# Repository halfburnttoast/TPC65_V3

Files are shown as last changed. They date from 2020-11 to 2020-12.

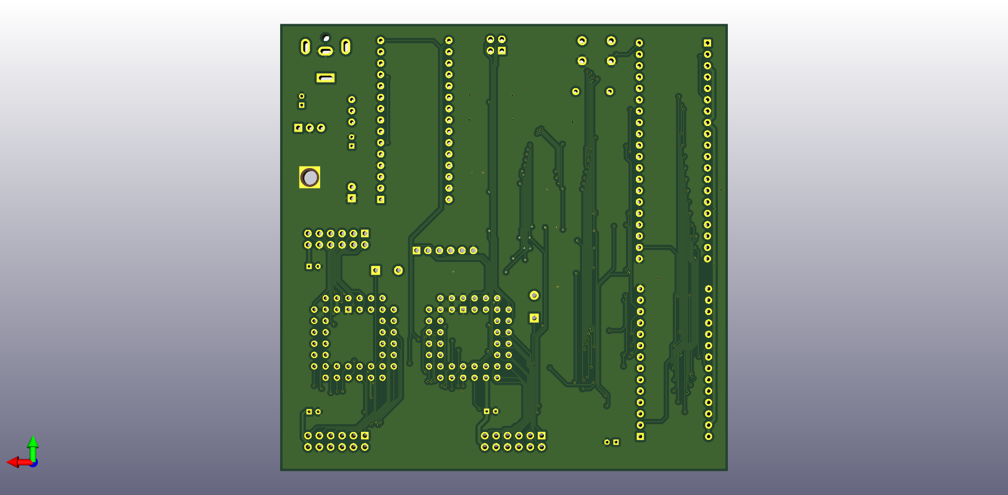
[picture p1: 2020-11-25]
tpc65816b.png

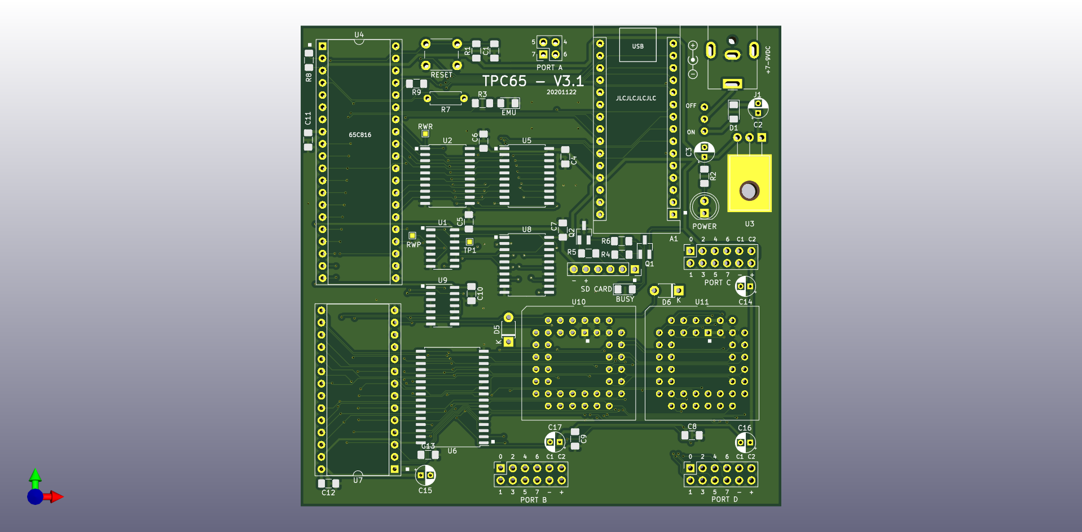
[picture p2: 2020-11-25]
tpc65816f.png

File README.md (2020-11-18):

# TPC65_V3
65C816 computer madness

This build replaces the TPC65-V2's CPU with a 65C816. It offers massive improvements, but requires additional circuitry to use bank switching.
On first boot, the CPU defaults to emulation mode. In emulation mode, the computer should be completely backwards compatible with V2 of this computer and all sofware. 

When emulation mode is turned off (see 65C816 datasheet for opcode sequence), the computer switches to 16-bit mode with a 24-bit (banked) address bus. 

Unfortunately, because of emulation mode, EEPROM must be located at the top-end of page 1 (0x000000 - 0x00FFFF). Because it follows the same memory map as V2, the memory map looks like this:

0x000000-0x007FFF - Base SRAM

0x008000-0x00BFFF - Memory-mapped IO

0x00C000-0x00FFFF - Base EEPROM + system vectors

Anything at or above 0x010000 is extended memory and requires banking through the 74x573 and 74x245. https://www.westerndesigncenter.com/wdc/documentation/w65c816s.pdf (page-44). 

The extended memory is currently mapped to the remaining address pins of the SRAM, which should give about 450K of extended RAM. Expanding EEPROM is not a priority as this computer has a built-in SD card module slot and is inteded to use the SD card for larger program loading.

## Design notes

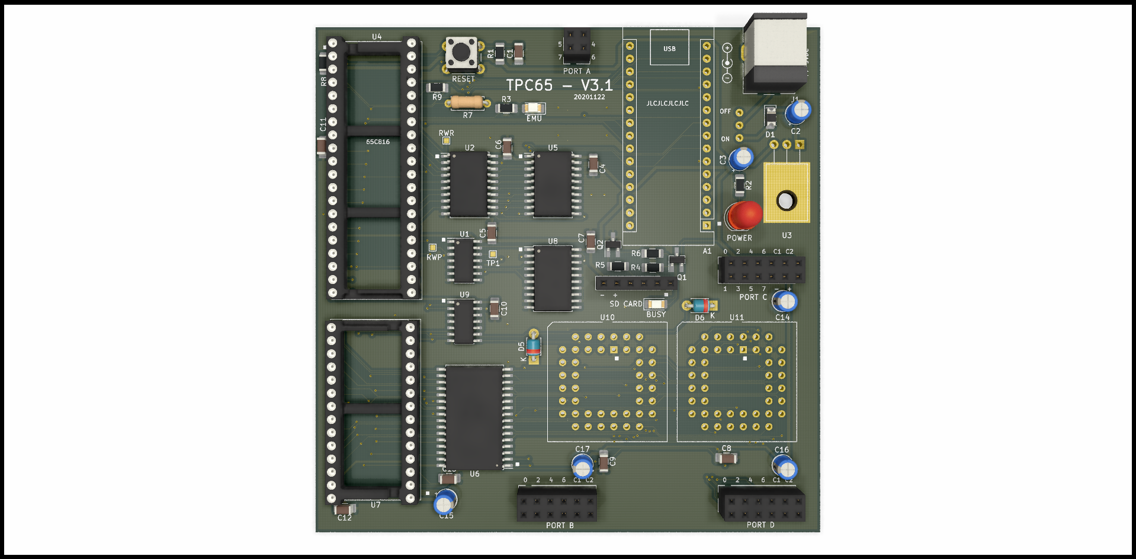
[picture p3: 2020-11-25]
tpc65816.png

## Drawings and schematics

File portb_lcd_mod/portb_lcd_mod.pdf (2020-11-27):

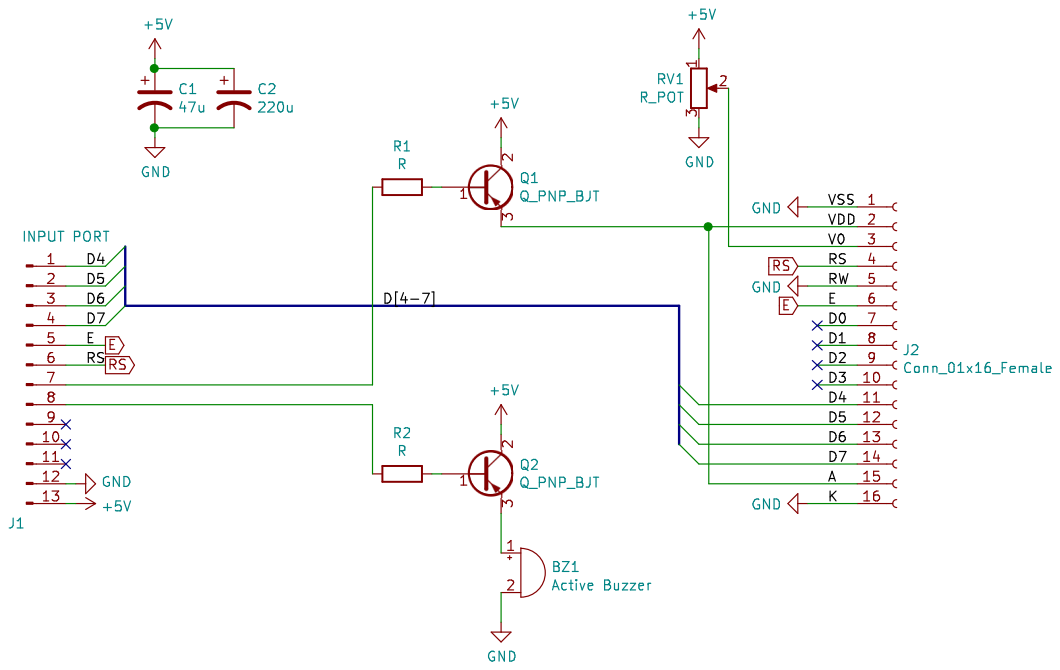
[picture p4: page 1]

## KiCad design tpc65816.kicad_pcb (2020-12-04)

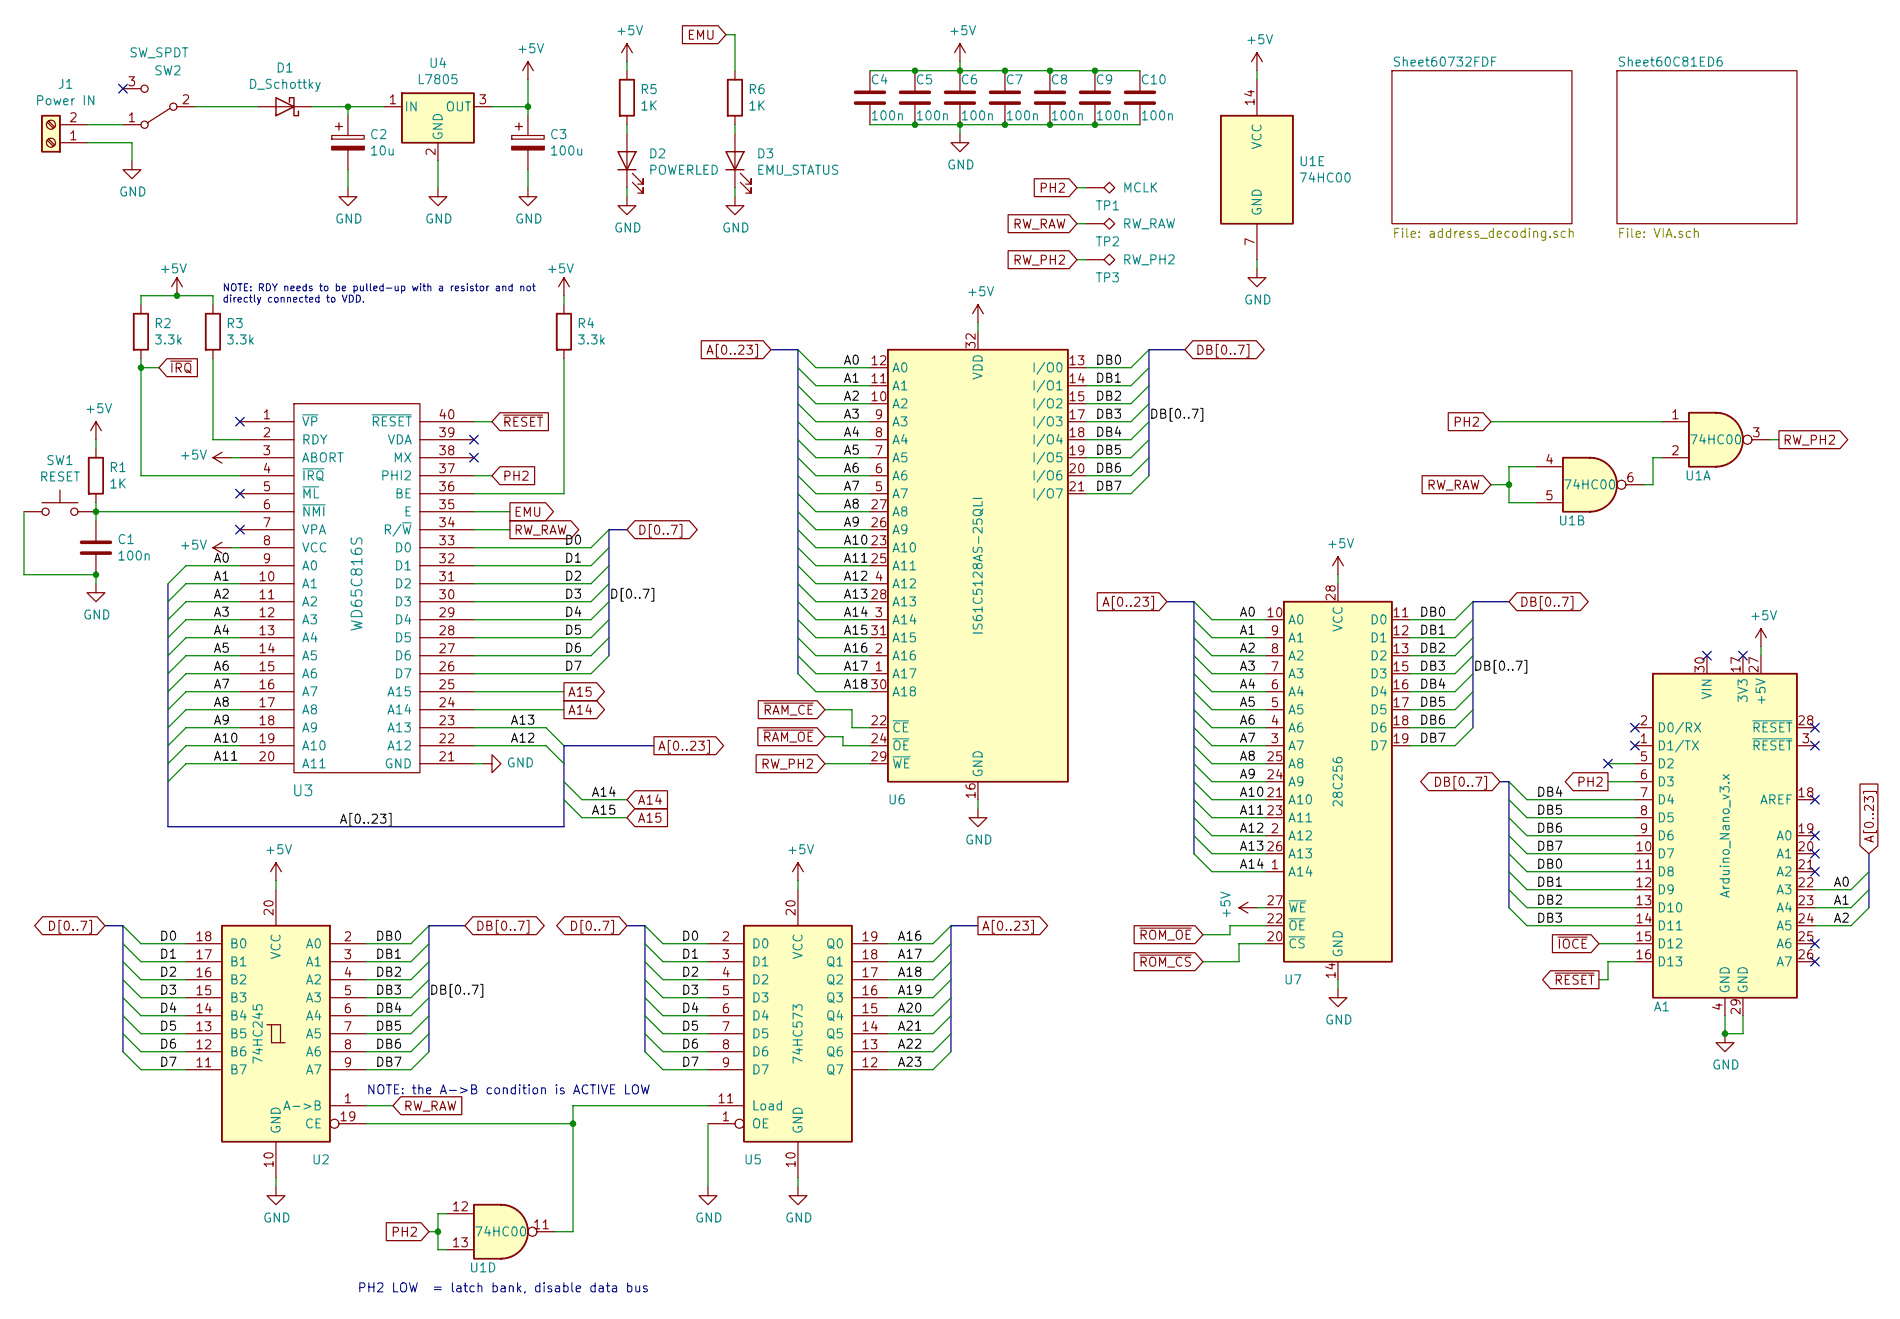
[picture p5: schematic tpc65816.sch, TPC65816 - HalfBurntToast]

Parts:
A1: Arduino_Nano_v3.x; Arduino_Nano
C1, C4, C5, C6, C7, C8, C9, C10: 100n; C_1206_3216Metric_Pad1.42x1.75mm_HandSolder
C2: 10u; CP_Radial_D4.0mm_P2.00mm
C3: 100u; CP_Radial_D4.0mm_P2.00mm
D1: D_Schottky; D_1206_3216Metric_Pad1.42x1.75mm_HandSolder
D2: POWERLED; LED_D5.0mm
D3: EMU_STATUS; LED_1206_3216Metric_Pad1.42x1.75mm_HandSolder
J1: Power IN; TerminalBlock_bornier-2_P5.08mm
R1, R5, R6: 1K; R_1206_3216Metric_Pad1.42x1.75mm_HandSolder
R2: 3.3k; R_Axial_DIN0207_L6.3mm_D2.5mm_P7.62mm_Horizontal
R3, R4: 3.3k; R_1206_3216Metric_Pad1.42x1.75mm_HandSolder
SW1: RESET; SW_PUSH_6mm
SW2: SW_SPDT; spdt_slide_switch
TP1: MCLK; TestPoint_Pad_1.0x1.0mm
TP2: RW_RAW; TestPoint_Pad_1.0x1.0mm
TP3: RW_PH2; TestPoint_Pad_1.0x1.0mm
U1: 74HC00; SOIC-14_3.9x8.7mm_P1.27mm
U2: 74HC245; SOIC-20W_7.5x12.8mm_P1.27mm
U3: WD65C816S; DIP-40_W15.24mm_Socket
U4: L7805; TO-220F-3_Horizontal_TabDown
U5: 74HC573; SOIC-20W_7.5x12.8mm_P1.27mm
U6: IS61C5128AS-25QLI; SSOP-32_11.305x20.495mm_P1.27mm
U7: 28C256; DIP-28_W15.24mm_Socket

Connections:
+5V: A1.27 (+5V), C3.1, C4.1, C5.1, C6.1, C7.1, C8.1, C9.1, C10.1, R1.1, R2.1, R3.1, R4.1, R5.1, U1.14 (VCC), U2.20 (VCC), U3.3 (ABORT), U3.8 (VCC), U4.3 (OUT), U5.20 (VCC), U6.32 (VDD), U7.27 (~WE), U7.28 (VCC); also elsewhere on the board
A0: A1.22 (A3), U3.9 (A0), U6.12 (A0), U7.10 (A0)
A1: A1.23 (A4), U3.10 (A1), U6.11 (A1), U7.9 (A1)
A2: A1.24 (A5), U3.11 (A2), U6.10 (A2), U7.8 (A2)
A3: U3.12 (A3), U6.9 (A3), U7.7 (A3); also elsewhere on the board
A4: U3.13 (A4), U6.8 (A4), U7.6 (A4); also elsewhere on the board
A5: U3.14 (A5), U6.7 (A5), U7.5 (A5); also elsewhere on the board
A6: U3.15 (A6), U6.6 (A6), U7.4 (A6); also elsewhere on the board
A7: U3.16 (A7), U6.5 (A7), U7.3 (A7); also elsewhere on the board
A8: U3.17 (A8), U6.27 (A8), U7.25 (A8); also elsewhere on the board
A9: U3.18 (A9), U6.26 (A9), U7.24 (A9)
A10: U3.19 (A10), U6.23 (A10), U7.21 (A10)
A11: U3.20 (A11), U6.25 (A11), U7.23 (A11)
A12: U3.22 (A12), U6.4 (A12), U7.2 (A12)
A13: U3.23 (A13), U6.28 (A13), U7.26 (A13)
A14: U3.24 (A14), U6.3 (A14), U7.1 (A14); also elsewhere on the board
A15: U3.25 (A15), U6.31 (A15); also elsewhere on the board
A16: U5.19 (Q0), U6.2 (A16); also elsewhere on the board
A17: U5.18 (Q1), U6.1 (A17); also elsewhere on the board
A18: U5.17 (Q2), U6.30 (A18); also elsewhere on the board
A19: U5.16 (Q3); also elsewhere on the board
A20: U5.15 (Q4); also elsewhere on the board
A21: U5.14 (Q5); also elsewhere on the board
A22: U5.13 (Q6); also elsewhere on the board
A23: U5.12 (Q7); also elsewhere on the board
D0: U2.18 (B0), U3.33 (D0), U5.2 (D0)
D1: U2.17 (B1), U3.32 (D1), U5.3 (D1)
D2: U2.16 (B2), U3.31 (D2), U5.4 (D2)
D3: U2.15 (B3), U3.30 (D3), U5.5 (D3)
D4: U2.14 (B4), U3.29 (D4), U5.6 (D4)
D5: U2.13 (B5), U3.28 (D5), U5.7 (D5)
D6: U2.12 (B6), U3.27 (D6), U5.8 (D6)
D7: U2.11 (B7), U3.26 (D7), U5.9 (D7)
DB0: A1.11 (D8), U2.2 (A0), U6.13 (I/O0), U7.11 (D0); also elsewhere on the board
DB1: A1.12 (D9), U2.3 (A1), U6.14 (I/O1), U7.12 (D1); also elsewhere on the board
DB2: A1.13 (D10), U2.4 (A2), U6.15 (I/O2), U7.13 (D2); also elsewhere on the board
DB3: A1.14 (D11), U2.5 (A3), U6.17 (I/O3), U7.15 (D3); also elsewhere on the board
DB4: A1.7 (D4), U2.6 (A4), U6.18 (I/O4), U7.16 (D4); also elsewhere on the board
DB5: A1.8 (D5), U2.7 (A5), U6.19 (I/O5), U7.17 (D5); also elsewhere on the board
DB6: A1.9 (D6), U2.8 (A6), U6.20 (I/O6), U7.18 (D6); also elsewhere on the board
DB7: A1.10 (D7), U2.9 (A7), U6.21 (I/O7), U7.19 (D7); also elsewhere on the board
EMU: R6.1, U3.35 (E)
GND: A1.4 (GND), A1.29 (GND), C1.2, C2.2, C3.2, C4.2, C5.2, C6.2, C7.2, C8.2, C9.2, C10.2, D2.1 (K), D3.1 (K), J1.1, SW1.1, U1.7 (GND), U2.10 (GND), U3.21 (GND), U4.2 (GND), U5.1 (OE), U5.10 (GND), U6.16 (GND), U7.14 (GND); also elsewhere on the board
unnamed: C1.1, R1.2, SW1.2, U3.6 (~NMI)
unnamed: C2.1, D1.1 (K), U4.1 (IN)
unnamed: D1.2 (A), SW2.2 (B)
unnamed: D2.2 (A), R5.2
unnamed: D3.2 (A), R6.2
unnamed: J1.2, SW2.1 (A)
unnamed: R3.2, U3.2 (RDY)
unnamed: R4.2, U3.36 (BE)
unnamed: U1.2, U1.6
unnamed: U1.11, U2.19 (CE), U5.11 (Load)
PH2: A1.6 (D3), TP1.1, U1.1, U1.12, U1.13, U3.37 (PHI2); also elsewhere on the board
RW_PH2: TP3.1, U1.3, U6.29 (~WE)
RW_RAW: TP2.1, U1.4, U1.5, U2.1 (A->B), U3.34 (R/~W); also elsewhere on the board
~IOCE: A1.15 (D12); also elsewhere on the board
~IRQ: R2.2, U3.4 (~IRQ); also elsewhere on the board
~RAM_CE: U6.22 (~CE), U6.24 (~OE); also elsewhere on the board
~RESET: A1.16 (D13), U3.40 (~RESET); also elsewhere on the board
~ROM_CS: U7.20 (~CS), U7.22 (~OE); also elsewhere on the board

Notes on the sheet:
NOTE: RDY needs to be pulled-up with a resistor and not directly connected to VDD.
NOTE: the A->B condition is ACTIVE LOW
PH2 LOW = latch bank, disable data bus

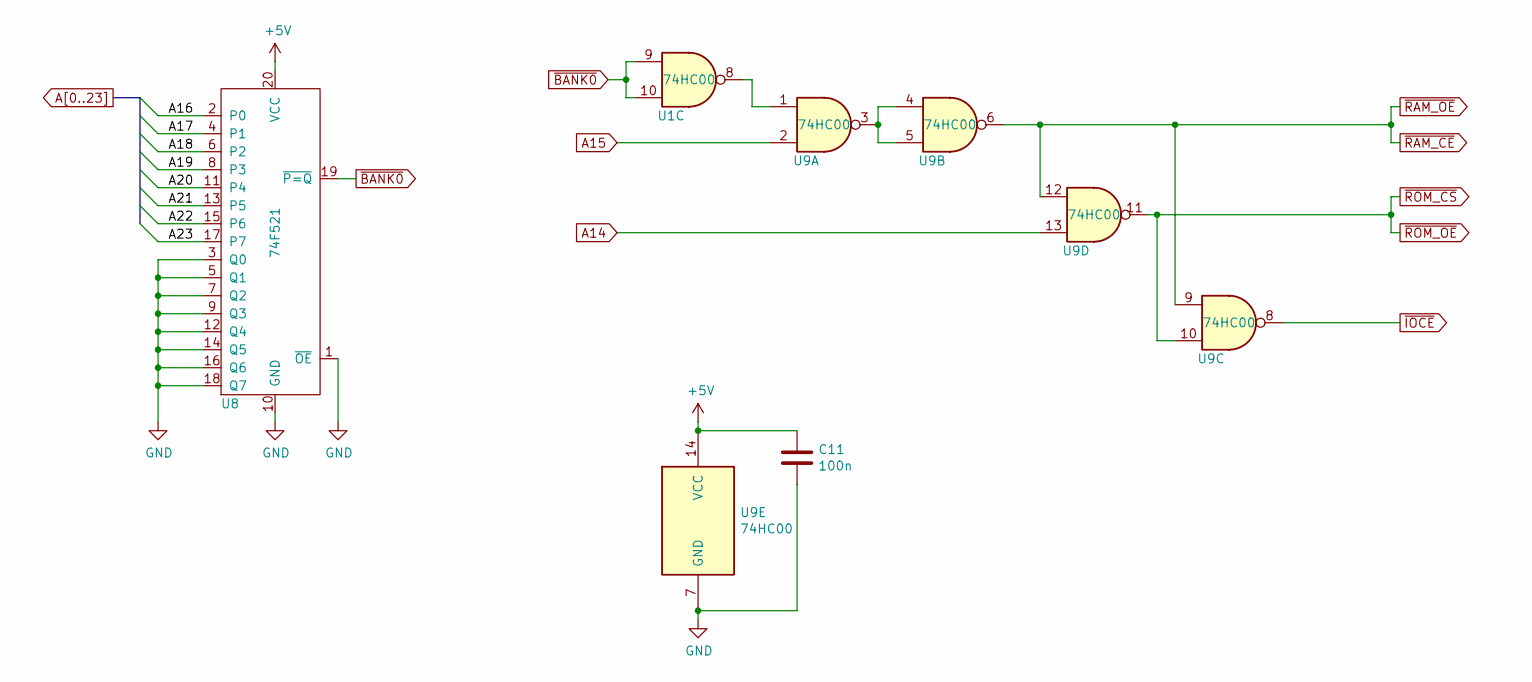
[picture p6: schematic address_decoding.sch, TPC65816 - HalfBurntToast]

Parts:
C11: 100n; C_1206_3216Metric_Pad1.42x1.75mm_HandSolder
U1, U9: 74HC00; SOIC-14_3.9x8.7mm_P1.27mm
U8: 74F521; SOIC-20W_7.5x12.8mm_P1.27mm

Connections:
+5V: C11.1, U8.20 (VCC), U9.14 (VCC); also elsewhere on the board
A14: U9.13; also elsewhere on the board
A15: U9.2; also elsewhere on the board
A16: U8.2 (P0); also elsewhere on the board
A17: U8.4 (P1); also elsewhere on the board
A18: U8.6 (P2); also elsewhere on the board
A19: U8.8 (P3); also elsewhere on the board
A20: U8.11 (P4); also elsewhere on the board
A21: U8.13 (P5); also elsewhere on the board
A22: U8.15 (P6); also elsewhere on the board
A23: U8.17 (P7); also elsewhere on the board
GND: C11.2, U8.1 (~OE), U8.3 (Q0), U8.5 (Q1), U8.7 (Q2), U8.9 (Q3), U8.10 (GND), U8.12 (Q4), U8.14 (Q5), U8.16 (Q6), U8.18 (Q7), U9.7 (GND); also elsewhere on the board
unnamed: U1.8, U9.1
unnamed: U9.3, U9.4, U9.5
~BANK0: U1.9, U1.10, U8.19 (~P=Q)
~IOCE: U9.8; also elsewhere on the board
~RAM_CE: U9.6, U9.9, U9.12; also elsewhere on the board
~ROM_CS: U9.10, U9.11; also elsewhere on the board

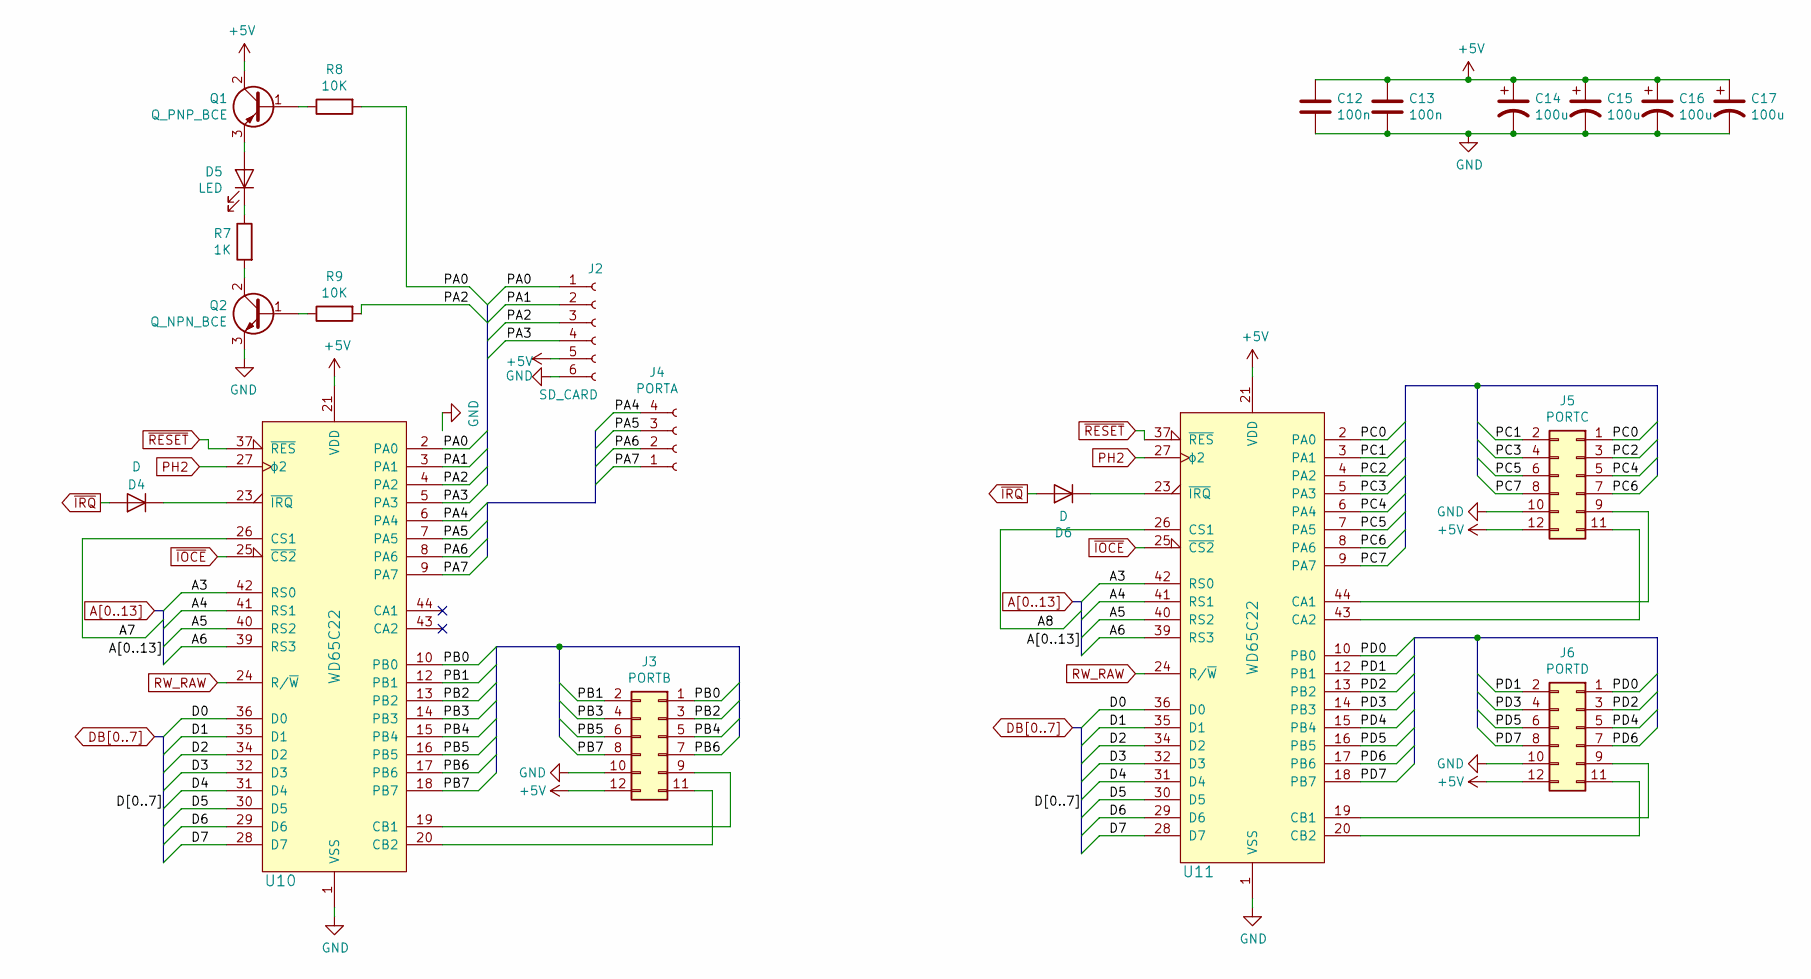
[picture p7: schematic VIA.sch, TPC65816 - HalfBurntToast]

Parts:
C12, C13: 100n; C_1206_3216Metric_Pad1.42x1.75mm_HandSolder
C14, C15, C16, C17: 100u; CP_Radial_D4.0mm_P2.00mm
D4, D6: D; D_T-1_P5.08mm_Horizontal
D5: LED; LED_1206_3216Metric_Pad1.42x1.75mm_HandSolder
J2: SD_CARD; PinSocket_1x06_P2.54mm_Vertical
J3: PORTB; PinSocket_2x06_P2.54mm_Vertical
J4: PORTA; PinSocket_2x02_P2.54mm_Vertical
J5: PORTC; PinSocket_2x06_P2.54mm_Vertical
J6: PORTD; PinSocket_2x06_P2.54mm_Vertical
Q1: Q_PNP_BCE; SOT-23_Handsoldering
Q2: Q_NPN_BCE; SOT-23_Handsoldering
R7: 1K; R_1206_3216Metric_Pad1.42x1.75mm_HandSolder
R8, R9: 10K; R_1206_3216Metric_Pad1.42x1.75mm_HandSolder
U10, U11: WD65C22; PLCC-44_THT-Socket

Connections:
+5V: C12.1, C13.1, C14.1, C15.1, C16.1, C17.1, J2.5, J3.12, J5.12, J6.12, Q1.2 (C), U10.21 (VDD), U11.21 (VDD); also elsewhere on the board
/Sheet60C81ED6/PA0: J2.1, R8.2, U10.2 (PA0)
/Sheet60C81ED6/PA1: J2.2, U10.3 (PA1)
/Sheet60C81ED6/PA2: J2.3, R9.2, U10.4 (PA2)
/Sheet60C81ED6/PA3: J2.4, U10.5 (PA3)
/Sheet60C81ED6/PA4: J4.4, U10.6 (PA4)
/Sheet60C81ED6/PA5: J4.3, U10.7 (PA5)
/Sheet60C81ED6/PA6: J4.2, U10.8 (PA6)
/Sheet60C81ED6/PA7: J4.1, U10.9 (PA7)
/Sheet60C81ED6/PB0: J3.1, U10.10 (PB0)
/Sheet60C81ED6/PB1: J3.2, U10.12 (PB1)
/Sheet60C81ED6/PB2: J3.3, U10.13 (PB2)
/Sheet60C81ED6/PB3: J3.4, U10.14 (PB3)
/Sheet60C81ED6/PB4: J3.5, U10.15 (PB4)
/Sheet60C81ED6/PB5: J3.6, U10.16 (PB5)
/Sheet60C81ED6/PB6: J3.7, U10.17 (PB6)
/Sheet60C81ED6/PB7: J3.8, U10.18 (PB7)
/Sheet60C81ED6/PC0: J5.1, U11.2 (PA0)
/Sheet60C81ED6/PC1: J5.2, U11.3 (PA1)
/Sheet60C81ED6/PC2: J5.3, U11.4 (PA2)
/Sheet60C81ED6/PC3: J5.4, U11.5 (PA3)
/Sheet60C81ED6/PC4: J5.5, U11.6 (PA4)
/Sheet60C81ED6/PC5: J5.6, U11.7 (PA5)
/Sheet60C81ED6/PC6: J5.7, U11.8 (PA6)
/Sheet60C81ED6/PC7: J5.8, U11.9 (PA7)
/Sheet60C81ED6/PD0: J6.1, U11.10 (PB0)
/Sheet60C81ED6/PD1: J6.2, U11.12 (PB1)
/Sheet60C81ED6/PD2: J6.3, U11.13 (PB2)
/Sheet60C81ED6/PD3: J6.4, U11.14 (PB3)
/Sheet60C81ED6/PD4: J6.5, U11.15 (PB4)
/Sheet60C81ED6/PD5: J6.6, U11.16 (PB5)
/Sheet60C81ED6/PD6: J6.7, U11.17 (PB6)
/Sheet60C81ED6/PD7: J6.8, U11.18 (PB7)
A3: U10.42 (RS0), U11.42 (RS0); also elsewhere on the board
A4: U10.41 (RS1), U11.41 (RS1); also elsewhere on the board
A5: U10.40 (RS2), U11.40 (RS2); also elsewhere on the board
A6: U10.39 (RS3), U11.39 (RS3); also elsewhere on the board
A7: U10.26 (CS1); also elsewhere on the board
A8: U11.26 (CS1); also elsewhere on the board
DB0: U10.36 (D0), U11.36 (D0); also elsewhere on the board
DB1: U10.35 (D1), U11.35 (D1); also elsewhere on the board
DB2: U10.34 (D2), U11.34 (D2); also elsewhere on the board
DB3: U10.32 (D3), U11.32 (D3); also elsewhere on the board
DB4: U10.31 (D4), U11.31 (D4); also elsewhere on the board
DB5: U10.30 (D5), U11.30 (D5); also elsewhere on the board
DB6: U10.29 (D6), U11.29 (D6); also elsewhere on the board
DB7: U10.28 (D7), U11.28 (D7); also elsewhere on the board
GND: C12.2, C13.2, C14.2, C15.2, C16.2, C17.2, J2.6, J3.10, J5.10, J6.10, Q2.3 (E), U10.1 (VSS), U11.1 (VSS); also elsewhere on the board
unnamed: D4.1 (K), U10.23 (~IRQ)
unnamed: D5.1 (K), R7.1
unnamed: D5.2 (A), Q1.3 (E)
unnamed: D6.1 (K), U11.23 (~IRQ)
unnamed: J3.9, U10.19 (CB1)
unnamed: J3.11, U10.20 (CB2)
unnamed: J5.9, U11.44 (CA1)
unnamed: J5.11, U11.43 (CA2)
unnamed: J6.9, U11.19 (CB1)
unnamed: J6.11, U11.20 (CB2)
unnamed: Q1.1 (B), R8.1
unnamed: Q2.1 (B), R9.1
unnamed: Q2.2 (C), R7.2
PH2: U10.27 (ϕ2), U11.27 (ϕ2); also elsewhere on the board
RW_RAW: U10.24 (R/~W), U11.24 (R/~W); also elsewhere on the board
~IOCE: U10.25 (~CS2), U11.25 (~CS2); also elsewhere on the board
~IRQ: D4.2 (A), D6.2 (A); also elsewhere on the board
~RESET: U10.37 (~RES), U11.37 (~RES); also elsewhere on the board

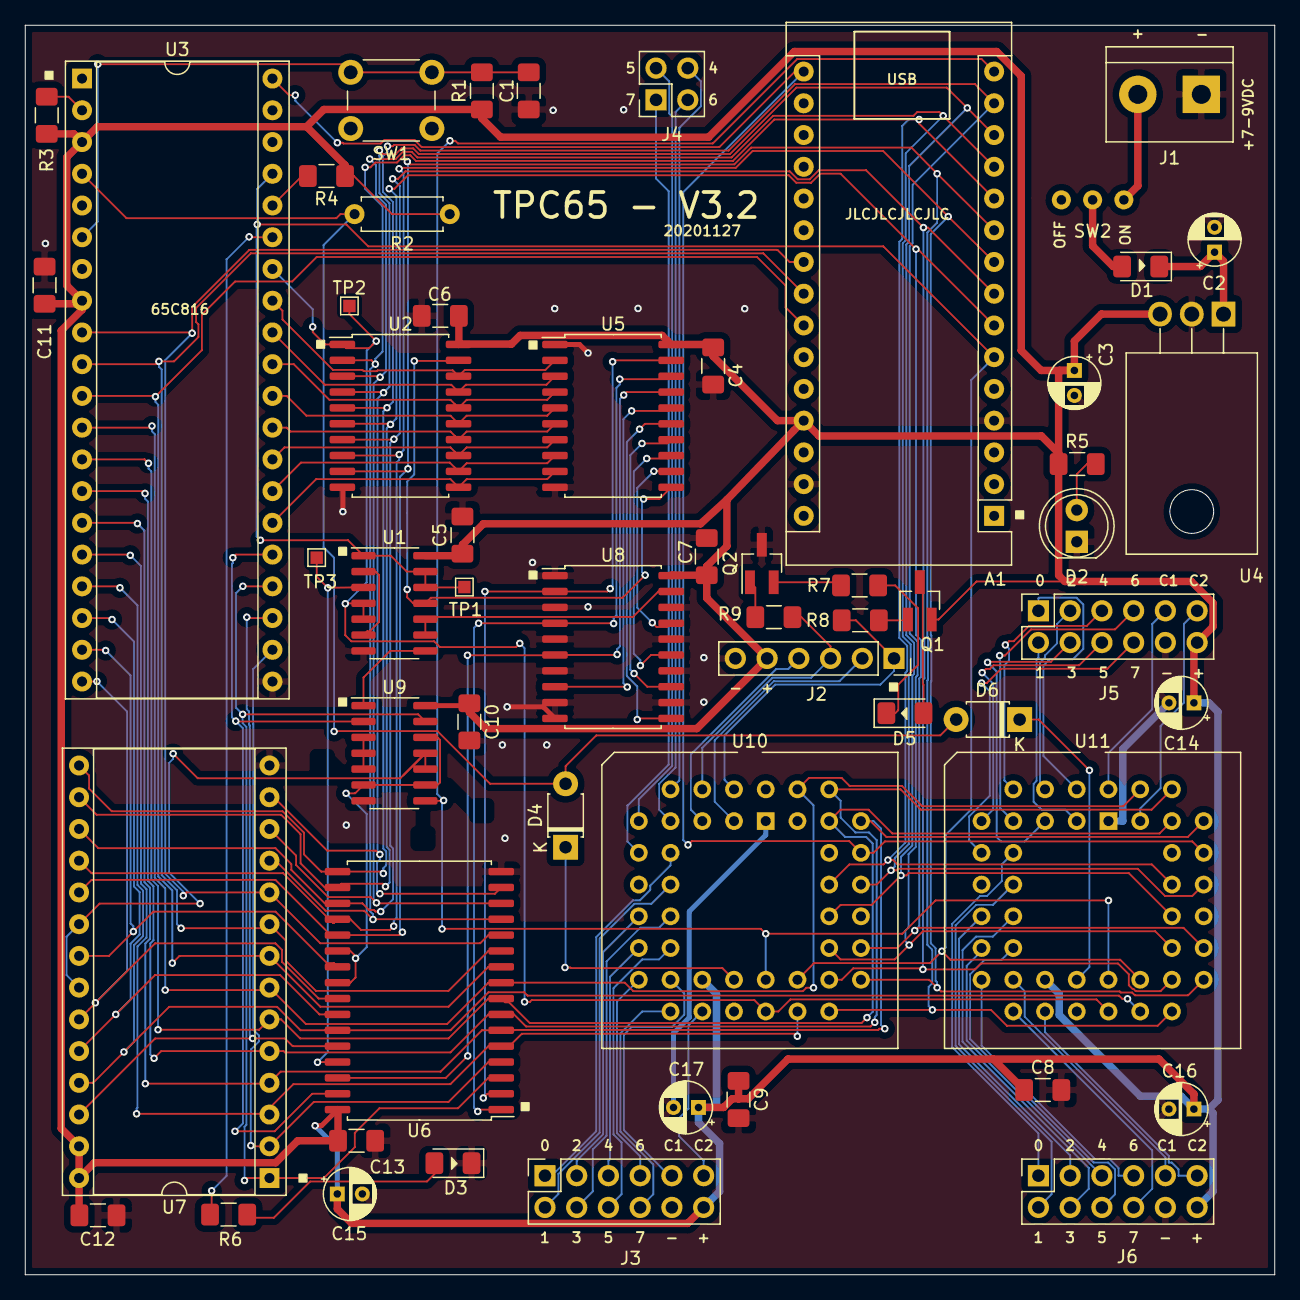
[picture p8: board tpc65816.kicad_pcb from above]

Board: 2 copper layers, 100.0 x 100.0 mm, 57 parts (0 on the bottom side), 109 nets.

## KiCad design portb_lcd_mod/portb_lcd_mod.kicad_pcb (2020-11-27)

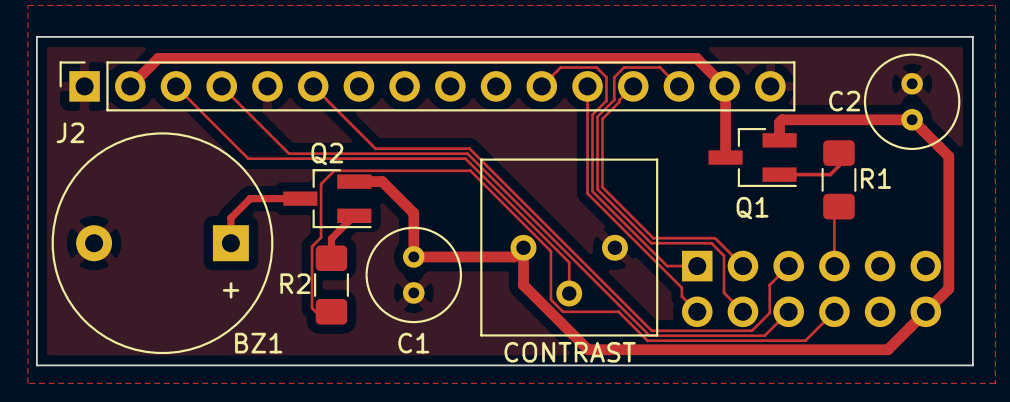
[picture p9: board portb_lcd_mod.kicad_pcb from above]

Board: 2 copper layers, 52.0 x 18.2 mm, 10 parts (1 on the bottom side), 15 nets.

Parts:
BZ1: Active Buzzer; Buzzer_12x9.5RM7.6
C1: 47u; C_Radial_D5.0mm_H7.0mm_P2.00mm
C2: 220u; C_Radial_D5.0mm_H7.0mm_P2.00mm
CONTRAST: R_POT; Potentiometer_Bourns_3386P_Vertical
J1: Conn_02x06_Odd_Even; PinHeader_2x06_P2.54mm_Vertical
J2: Conn_01x16_Female; PinSocket_1x16_P2.54mm_Vertical
Q1, Q2: Q_PNP_BJT; SOT-23_Handsoldering
R1, R2: R; R_1206_3216Metric_Pad1.42x1.75mm_HandSolder

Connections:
+5V: C1.1, C2.1, CONTRAST.1, J1.12, Q1.2, Q2.2
/A: J2.2, J2.15, Q1.3
/D4: J1.1, J2.11
/D5: J1.2, J2.12
/D6: J1.3, J2.13
/D7: J1.4, J2.14
/V0: CONTRAST.2, J2.3
E: J1.5, J2.6
GND: BZ1.2, C1.2, C2.2, CONTRAST.3, J1.10, J2.1, J2.5, J2.16
unnamed: BZ1.1, Q2.3
unnamed: J1.7, R1.2
unnamed: J1.8, R2.2
unnamed: Q1.1, R1.1
unnamed: Q2.1, R2.1
RS: J1.6, J2.4

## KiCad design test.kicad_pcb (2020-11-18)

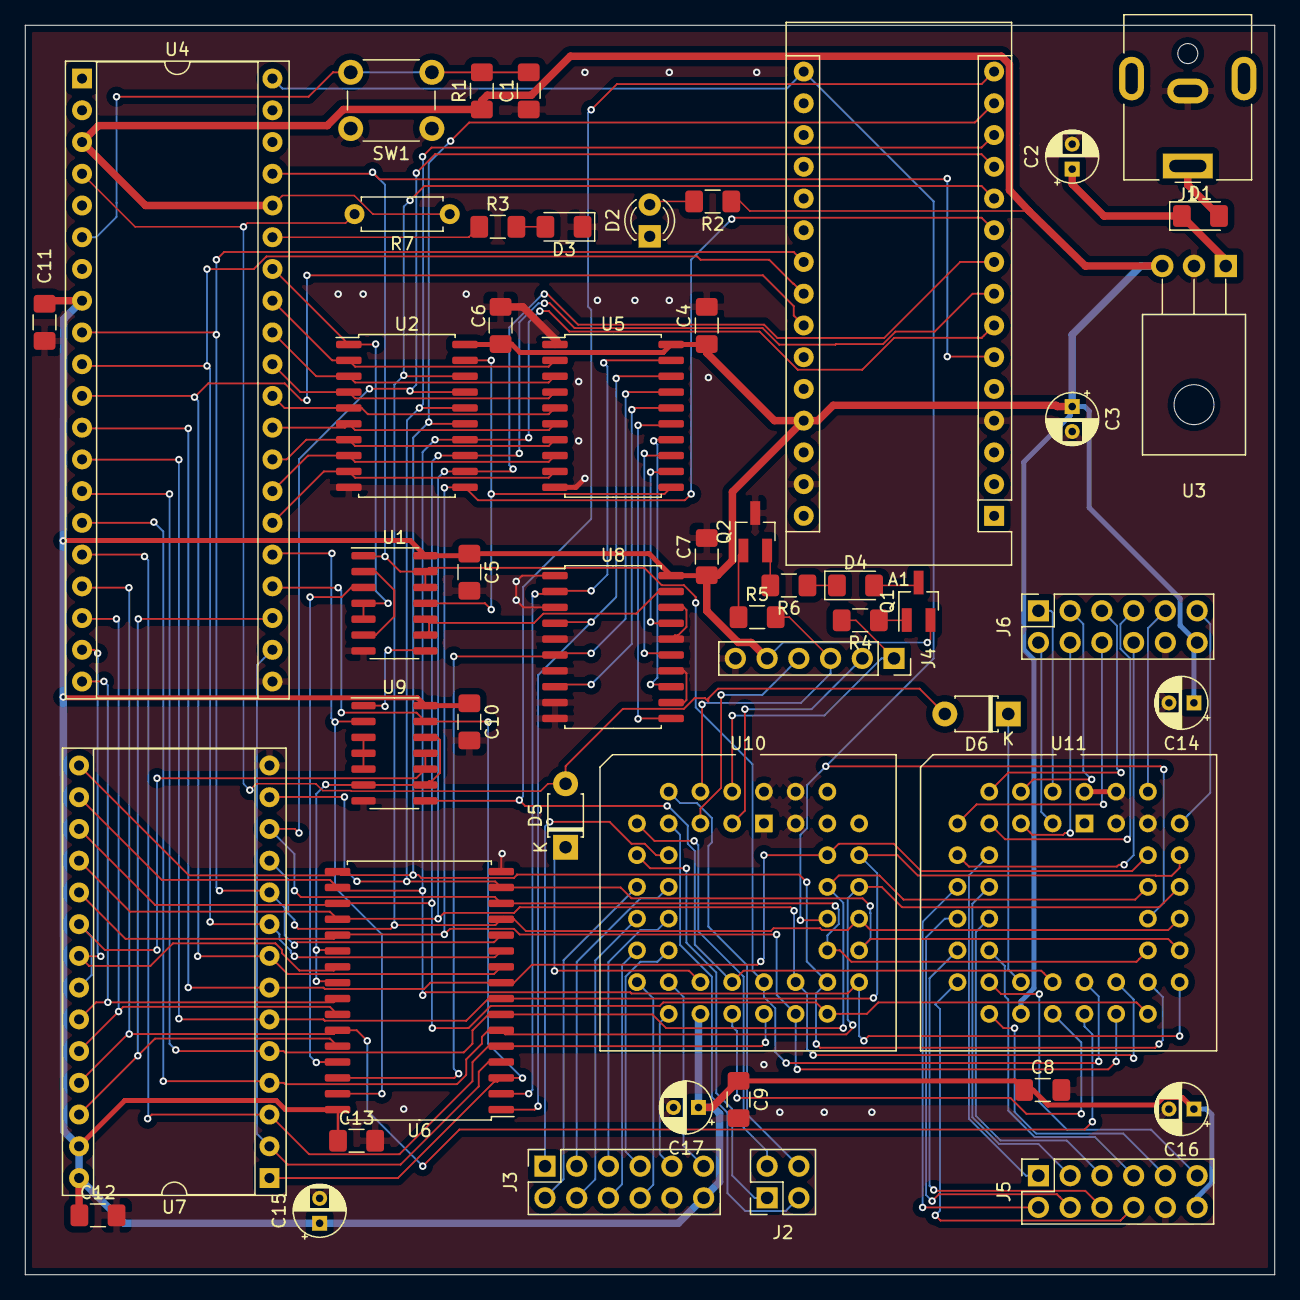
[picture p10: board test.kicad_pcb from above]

Board: 2 copper layers, 100.0 x 100.0 mm, 51 parts (0 on the bottom side), 107 nets.

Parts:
A1: Arduino_Nano_v3.x; Arduino_Nano
C1, C4, C5, C6, C7, C8, C9, C10, C11, C12, C13: 100n; C_1206_3216Metric_Pad1.42x1.75mm_HandSolder
C2: 10u; CP_Radial_D4.0mm_P2.00mm
C3, C14, C15, C16, C17: 100u; CP_Radial_D4.0mm_P2.00mm
D1: D_Schottky; D_1206_3216Metric_Pad1.42x1.75mm_HandSolder
D2: POWERLED; LED_D3.0mm
D3: EMU_STATUS; LED_1206_3216Metric_Pad1.42x1.75mm_HandSolder
D4: LED; LED_1206_3216Metric_Pad1.42x1.75mm_HandSolder
D5, D6: D; D_T-1_P5.08mm_Horizontal
J1: Barrel_Jack; BarrelJack_CUI_PJ-063AH_Horizontal
J2: PORTA; PinSocket_2x02_P2.54mm_Vertical
J3: PORTB; PinSocket_2x06_P2.54mm_Vertical
J4: SD_CARD; PinSocket_1x06_P2.54mm_Vertical
J5: PORTD; PinSocket_2x06_P2.54mm_Vertical
J6: PORTC; PinSocket_2x06_P2.54mm_Vertical
Q1: Q_PNP_BCE; SOT-23_Handsoldering
Q2: Q_NPN_BCE; SOT-23_Handsoldering
R1, R2, R3, R6: 1K; R_1206_3216Metric_Pad1.42x1.75mm_HandSolder
R4, R5: 10K; R_1206_3216Metric_Pad1.42x1.75mm_HandSolder
R7: 3.3k; R_Axial_DIN0207_L6.3mm_D2.5mm_P7.62mm_Horizontal
SW1: RESET; SW_PUSH_6mm
U1, U9: 74HC00; SOIC-14_3.9x8.7mm_P1.27mm
U2: 74LS245; SOIC-20W_7.5x12.8mm_P1.27mm
U3: L7805; TO-126-3_Horizontal_TabDown
U4: WD65C816S; DIP-40_W15.24mm_Socket
U5: 74LS573; SOIC-20W_7.5x12.8mm_P1.27mm
U6: IS61C5128AS-25QLI; SSOP-32_11.305x20.495mm_P1.27mm
U7: 28C256; DIP-28_W15.24mm_Socket
U8: 74F521; SOIC-20W_7.5x12.8mm_P1.27mm
U10, U11: WD65C22; PLCC-44_THT-Socket

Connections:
+5V: A1.27, C3.1, C4.1, C5.1, C6.1, C7.1, C8.1, C9.1, C10.1, C11.1, C12.1, C13.1, C14.1, C15.1, C16.1, C17.1, J3.12, J4.5, J5.12, J6.12, Q1.2, R1.1, R2.1, R7.1, U1.14, U2.20, U3.3, U4.3, U4.8, U4.36, U5.20, U6.32, U7.27, U7.28, U8.20, U9.14, U10.20, U11.20
/Sheet60C81ED6/PA0: J4.1, R4.2, U10.2
/Sheet60C81ED6/PA1: J4.2, U10.3
/Sheet60C81ED6/PA2: J4.3, R5.2, U10.4
/Sheet60C81ED6/PA3: J4.4, U10.5
/Sheet60C81ED6/PA4: J2.4, U10.6
/Sheet60C81ED6/PA5: J2.3, U10.7
/Sheet60C81ED6/PA6: J2.2, U10.8
/Sheet60C81ED6/PA7: J2.1, U10.9
/Sheet60C81ED6/PB0: J3.1, U10.10
/Sheet60C81ED6/PB1: J3.2, U10.11
/Sheet60C81ED6/PB2: J3.3, U10.12
/Sheet60C81ED6/PB3: J3.4, U10.13
/Sheet60C81ED6/PB4: J3.5, U10.14
/Sheet60C81ED6/PB5: J3.6, U10.15
/Sheet60C81ED6/PB6: J3.7, U10.16
/Sheet60C81ED6/PB7: J3.8, U10.17
/Sheet60C81ED6/PC0: J6.1, U11.2
/Sheet60C81ED6/PC1: J6.2, U11.3
/Sheet60C81ED6/PC2: J6.3, U11.4
/Sheet60C81ED6/PC3: J6.4, U11.5
/Sheet60C81ED6/PC4: J6.5, U11.6
/Sheet60C81ED6/PC5: J6.6, U11.7
/Sheet60C81ED6/PC6: J6.7, U11.8
/Sheet60C81ED6/PC7: J6.8, U11.9
/Sheet60C81ED6/PD0: J5.1, U11.10
/Sheet60C81ED6/PD1: J5.2, U11.11
/Sheet60C81ED6/PD2: J5.3, U11.12
/Sheet60C81ED6/PD3: J5.4, U11.13
/Sheet60C81ED6/PD4: J5.5, U11.14
/Sheet60C81ED6/PD5: J5.6, U11.15
/Sheet60C81ED6/PD6: J5.7, U11.16
/Sheet60C81ED6/PD7: J5.8, U11.17
A0: A1.22, U4.9, U6.12, U7.10
A1: A1.23, U4.10, U6.11, U7.9
A2: A1.24, U4.11, U6.10, U7.8
A3: U4.12, U6.9, U7.7, U10.38, U11.38
A4: U4.13, U6.8, U7.6, U10.37, U11.37
A5: U4.14, U6.7, U7.5, U10.36, U11.36
A6: U4.15, U6.6, U7.4, U10.35, U11.35
A7: U4.16, U6.5, U7.3, U10.24
A8: U4.17, U6.27, U7.25, U11.24
A9: U4.18, U6.26, U7.24
A10: U4.19, U6.23, U7.21
A11: U4.20, U6.25, U7.23
A12: U4.22, U6.4, U7.2
A13: U4.23, U6.28, U7.26
A14: U4.24, U6.3, U7.1, U9.13
A15: U4.25, U6.31, U9.2
A16: U5.19, U6.2, U8.2
A17: U5.18, U6.1, U8.4
A18: U5.17, U6.30, U8.6
A19: U5.16, U8.8
A20: U5.15, U8.11
A21: U5.14, U8.13
A22: U5.13, U8.15
A23: U5.12, U8.17
D0: U2.2, U4.33, U5.2
D1: U2.3, U4.32, U5.3
D2: U2.4, U4.31, U5.4
D3: U2.5, U4.30, U5.5
D4: U2.6, U4.29, U5.6
D5: U2.7, U4.28, U5.7
D6: U2.8, U4.27, U5.8
D7: U2.9, U4.26, U5.9
DB0: A1.11, U2.18, U6.13, U7.11, U10.33, U11.33
DB1: A1.12, U2.17, U6.14, U7.12, U10.32, U11.32
DB2: A1.13, U2.16, U6.15, U7.13, U10.31, U11.31
DB3: A1.14, U2.15, U6.17, U7.15, U10.30, U11.30
DB4: A1.7, U2.14, U6.18, U7.16, U10.29, U11.29
DB5: A1.8, U2.13, U6.19, U7.17, U10.28, U11.28
DB6: A1.9, U2.12, U6.20, U7.18, U10.27, U11.27
DB7: A1.10, U2.11, U6.21, U7.19, U10.26, U11.26
EMU: R3.1, U4.35
GND: A1.4, A1.29, C1.2, C2.2, C3.2, C4.2, C5.2, C6.2, C7.2, C8.2, C9.2, C10.2, C11.2, C12.2, C13.2, C14.2, C15.2, C16.2, C17.2, D2.1, D3.1, J1.2, J3.10, J4.6, J5.10, J6.10, Q2.3, SW1.1, U1.7, U2.10, U3.2, U4.21, U5.1, U5.10, U6.16, U7.14, U8.1, U8.3, U8.5, U8.7, U8.9, U8.10, U8.12, U8.14, U8.16, U8.18, U9.7, U10.1, U10.42, U10.43, U10.44, U11.1, U11.41, U11.42, U11.43, U11.44
unnamed: C1.1, R1.2, SW1.2, U4.6
unnamed: C2.1, D1.1, U3.1
unnamed: D1.2, J1.1
unnamed: D2.2, R2.2
unnamed: D3.2, R3.2
unnamed: D4.1, R6.1
unnamed: D4.2, Q1.3
unnamed: D5.1, U10.21
unnamed: D6.1, U11.21
unnamed: J3.9, U10.18
unnamed: J3.11, U10.19
unnamed: J5.9, U11.18
unnamed: J5.11, U11.19
unnamed: J6.9, U11.40
unnamed: J6.11, U11.39
unnamed: Q1.1, R4.1
unnamed: Q2.1, R5.1
unnamed: Q2.2, R6.2
unnamed: U1.2, U1.6
unnamed: U1.8, U9.1
unnamed: U1.11, U2.19, U5.11
unnamed: U9.3, U9.4, U9.5
PH2: A1.6, U1.1, U1.12, U1.13, U4.37, U10.25, U11.25
RW_RAW: U10.22, U11.22
RW_RAW_PH2: U1.3, U6.29
RW_RAW_RAW: U1.4, U1.5, U2.1, U4.34
~BANK0: U1.9, U1.10, U8.19
~IOCE: A1.15, U9.8, U10.23, U11.23
~IRQ: D5.2, D6.2, R7.2, U4.4
~RAM_CE: U6.22, U6.24, U9.6, U9.9, U9.12
~RESET: A1.16, U4.40, U10.34, U11.34
~ROM_CS: U7.20, U7.22, U9.10, U9.11

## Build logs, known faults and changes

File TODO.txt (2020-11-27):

Wrong footprint for barrel jack
Wrong footprint for voltage reg
Move switch away from cap
Flip bus tranciever A and B
Make PLCC symbol + check footprint for 65C22

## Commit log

2020-11-18 Initial layout - NOT VERIFIED TO WORK
    Initial layout of PCB. There's a very high chance there are errors made either in the schematic and/or layout. The chip layout may also not be as tidy or efficient as it can be.
    [VIA.sch, address_decoding.sch, test.kicad_pcb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]
2020-11-19 Edit to main schematic and layout
    [address_decoding.sch, tpc65816.kicad_pcb, tpc65816.sch]
2020-11-20 Minor cleanup and repositioning - fabricated
    Schematic verified. Added power switch. Repositioned PORT A. Cleanup of some traces. Added silkscreen markings.
    Board has been sent to fabrication as of this commit.
    [VIA.sch, tpc65816.kicad_pcb, tpc65816.sch]
2020-11-21 Fixed floating rdy pin
    [tpc65816.kicad_pcb, tpc65816.sch]
2020-11-22 Fill update
    [tpc65816.kicad_pcb, tpc65816.sch]
2020-11-22 Fix to RDY pin
    RDY needs to be pulled up with a resistor and not linked to VDD directly. Unlike the 65c02, RDY on the 65c816 is bidirectional and can, under some circumstances, attempt to pull itself down. If it's directly connected to VDD, it will attempt to sink VDD and short out. WDC seems to recommend using 3.3K resistors as pullups. I'm not sure how other values would perform. BE is now pulled up with a resistor too, which is recommended by WDC for reasons I'm not sure about.
    [tpc65816.kicad_pcb, tpc65816.sch]
2020-11-25 Track cleanup
    [tpc65816.kicad_pcb]
2020-11-27 MAJOR FIXES - UNTESTED
    Fixes for voltage regulator and barrel jack footprint. Fix for 245 direction. Fix for 65C22 PLCC pin layout. Complete rerouting of board.
    [VIA.sch, address_decoding.sch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]
2020-12-04 Fix for bank decoder logic
    [VIA.sch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]
